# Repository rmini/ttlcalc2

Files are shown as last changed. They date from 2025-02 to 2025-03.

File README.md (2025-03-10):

# TtlCalc2 Project

## Overview

The TtlCalc2 project is a recreation of the original (now TtlCalc1) project from 2005 that implemented a four-function floating point calculator in TTL logic without a microprocessor.

This version uses multilayer PCBs and Nixie tube and neon indicators for the display, whereas the original used wire wrap boards and LED 7-segment displays. Both versions share the same architecture, with separate (Harvard architecture) 8-bit data and 12-bit instruction address spaces, a 4-bit data path, and a 16-bit instruction word.

The goal of the original was to gain experience designing and implementing a processor with these techniques with an eye towards taking on the design of a more capable minicomputer. 

This repository contains the hardware and software components for the TtlCalc2 project, including simulation tools, assembly code, and documentation.

## Board renders

### Main logic board (processor)
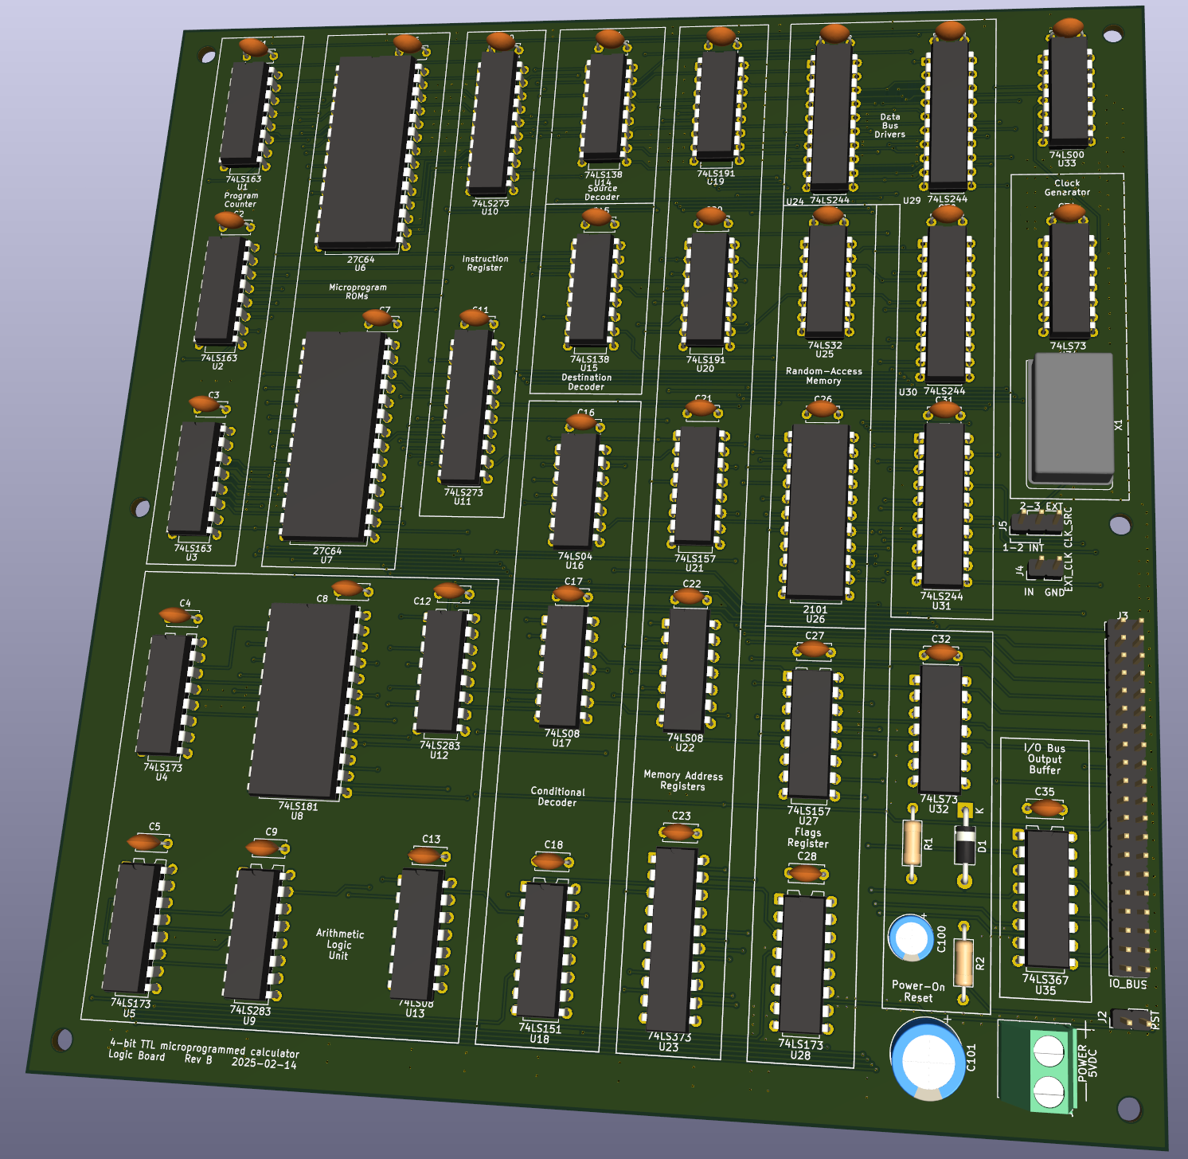
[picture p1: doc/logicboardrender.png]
Main logic board render


### Display driver board
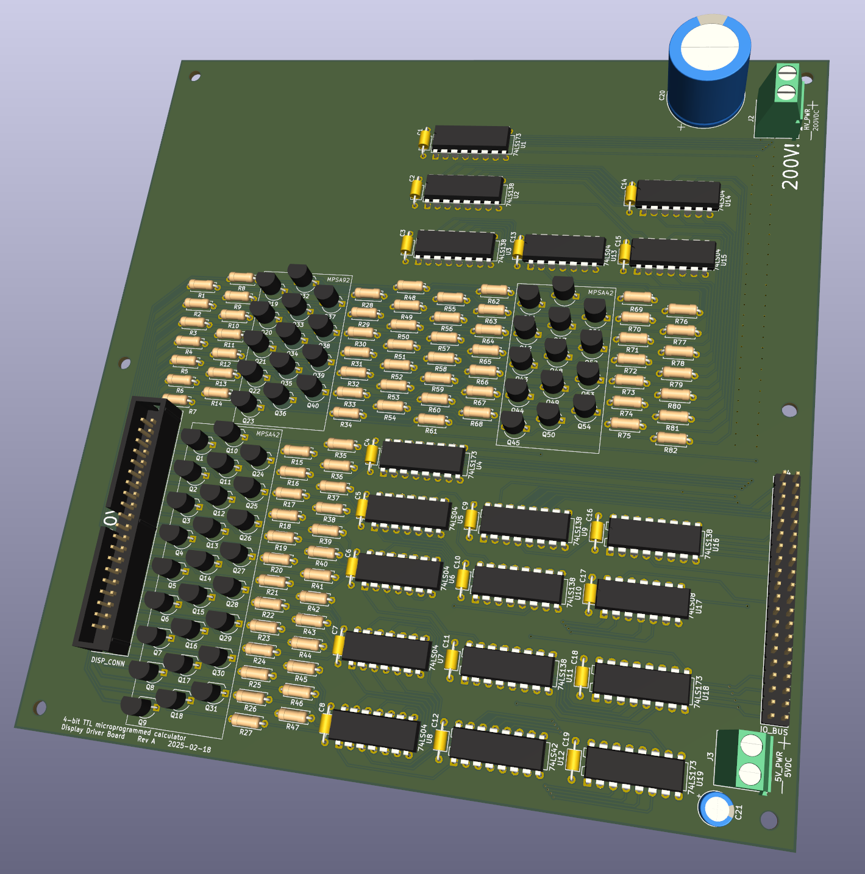
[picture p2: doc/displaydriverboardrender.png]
Display driver board render


### Front panel display board (Nixies and neons)
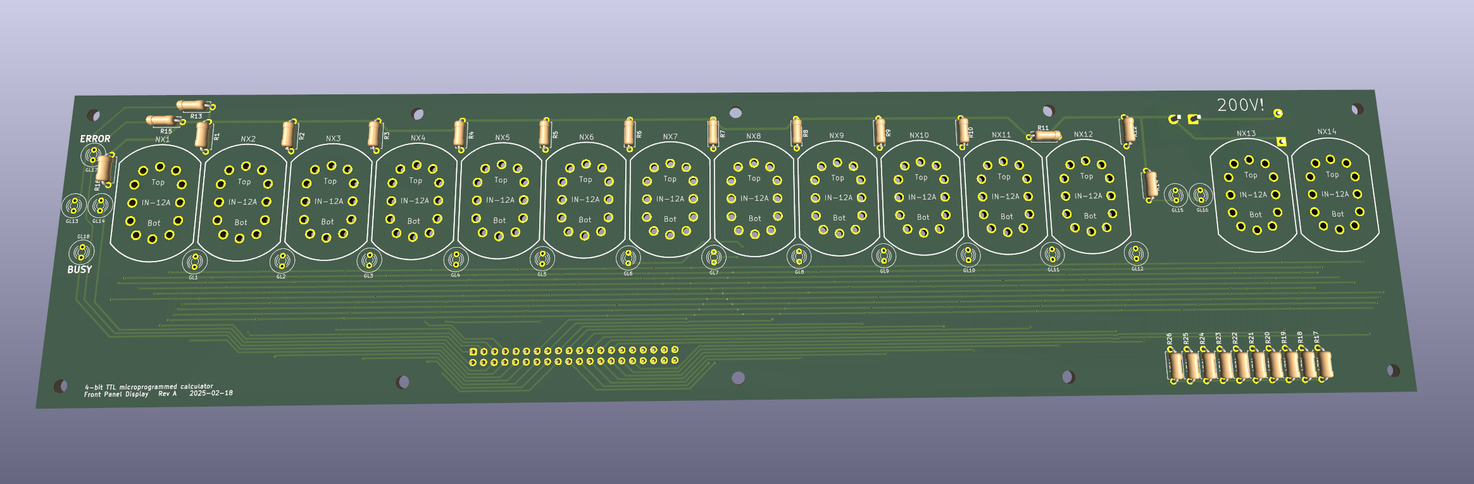
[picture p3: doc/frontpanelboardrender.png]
Front panel display board render


## Directory Structure

 * [`hw/`](hw/): KiCad schematic and PCB designs for the hardware
 * [`sw/`](sw/): Software for the calculator (microinstruction ROMs)
 * [`doc/`](doc/): Design and implementation documentation
 * [`TtlCalcSim/`](TtlCalcSim/): Simulator for the calculator hardware

## Hardware

The [`hw`](hw) directory contains KiCad project files for the TtlCalc2 hardware design.

- [`ttlcalc2/`](hw/ttlcalc2/): Logic board hardware design files.
- [`ttlcalc2_display/`](hw/ttlcalc2_display/): Display driver module design files.
- [`ttlcalc2_front/`](hw/ttlcalc2_front/): Front panel design files.

TODO: The keyboard and keyboard interface still needs to be designed.

### Gerber Files

The `hw/ttlcalc2/gerbers` directory contains the Gerber files for PCB manufacturing.

## Software

The [`sw`](sw/) directory contains assembly code for the TtlCalc2 project. This project uses the [customasm](https://github.com/hlorenzi/customasm) assembler to generate the microcode stream.

- [`ttlcalc2.asm`](sw/ttlcalc2.asm): Mnemonic definitions for the TtlCalc2 microcode.
- [`fib.asm`](sw/fib.asm): Assembly code for calculating Fibonacci numbers.

TODO: Port original ttlcalc assembly source code to new customasm syntax.

### Assembling

For example, to build the Fibonacci code, run:
```sh
customasm fib.asm
```
This generates `fib.bin` which you can then load into the simulator and run.

## Documentation

The [`doc`](doc/) directory contains documentation for the TtlCalc2 project.

## Simulation

The [`TtlCalcSim`](TtlCalcSim/) directory contains the simulation tools for the TtlCalc2 project. The simulator is implemented as a C#/.NET 9.0 console application.

- [`TtlCalcSim/`](TtlCalcSim/TtlCalcSim/): Core simulation library.
- [`TtlCalcSim.ConsoleUI/`](TtlCalcSim/TtlCalcSim.ConsoleUI/): Console-based user interface for the simulator.
- [`TtlCalcSim.Tests/`](TtlCalcSim/TtlCalcSim.Tests/): Unit tests for the simulation library.

### Building the Simulator

To build the simulator, open the TtlCalcSim.sln solution file in Visual Studio and build the project, or use the following command from the TtlCalcSim directory:
```sh
dotnet build
```

### Running Tests

To run the unit tests, use the following command from the TtlCalcSim directory:
```sh
dotnet test
```

### Running the simulator

Either run the simulator executable after building, or run it via the `dotnet` command:
```sh
dotnet run --project TtlCalcSim.ConsoleUI
```

## License

This project is licensed under the MIT License. See the LICENSE file for details.

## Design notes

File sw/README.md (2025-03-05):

# Software for Ttlcalc2

## Assembling

Use customasm from https://github.com/hlorenzi/customasm

For example, to build the Fibonacci code, run `customasm fib.asm`. This generates `fib.bin` which you can then load into the simulator and run.

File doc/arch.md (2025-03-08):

# Overview

The processor is driven by a 16-bit wide microprogram ROM with a 12-bit address. Each instruction directly controls the source that drives the 4-bit data bus and the destination that receives this data. 

Each instruction is either a branch instruction or a data movement instruction.

The ALU is implemented around a 74LS181, a 4-bit arithmetic logic unit (ALU) chip used in many early computers. Additional adders are integrated to allow direct Binary-Coded Decimal (BCD) operations. AND gates are used to provide a flag output for an all-ones result, indicating specific conditions during operations.

RAM and I/O address spaces are separate, but both are driven by the same address registers. The address bus can be driven either from the combined H/L registers or from the 4-bit immediate instruction field via zero-extension. This allows quick access to the first 16 memory and I/O addresses.

# Data path

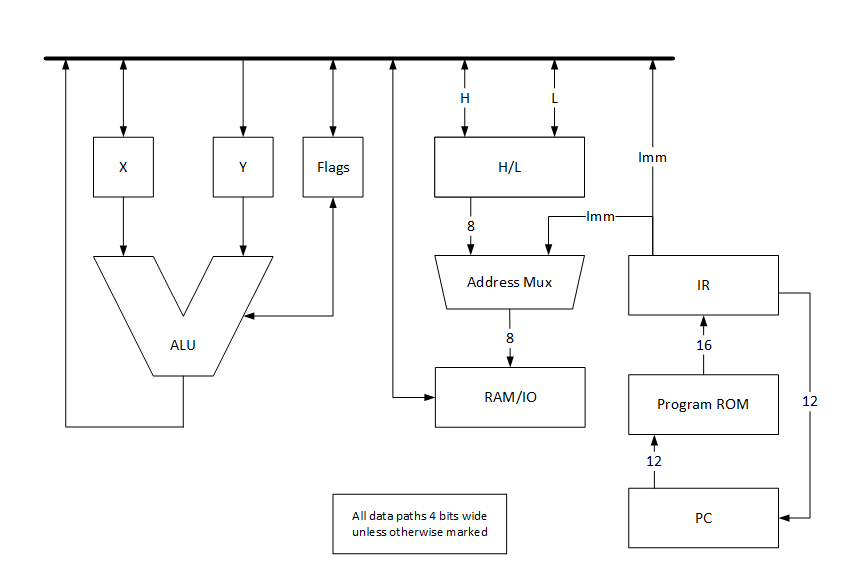
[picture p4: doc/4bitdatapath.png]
data path diagram


## Data Registers

Four-bit registers:

* X, Y: ALU source registers
* Flags (set on ALU operations or explicit target)
  * C: ALU carry in/out (bit 0)
  * E: ALU equal (all ones output) (bit 1)
  * X: Auxiliary flag 1 (bit 2)
  * Y: Auxiliary flag 2 (bit 3)
* H/L: Address registers, combined to make an 8-bit address
  * H: High 4 bits of address (bits 7..4)
  * L: Low 4 bits of address (bits 3..0)
  * Optional post-increment/decrement

## Instruction Registers
* PC: Implemented with a 12-bit presettable counter
* IR: 16-bit 

## Memory
Memory is implemented with an Intel 2101 (or equivalent) 256 x 4-bit NMOS static RAM with separate read and write ports.

## I/O
Separate 4-bit data input and output ports are buffered to and from the internal data bus.

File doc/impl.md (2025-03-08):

# Implementation notes

## Clock and power-on reset logic
The processor uses a two-phase non-overlapping clock derived from a TTL-compatible crystal oscillator module or an external input. This type of clock ensures that there are no overlapping periods where both phases are active, which helps to avoid timing issues and race conditions in the processor's operation. An entire two-phase instruction cycle takes 4 input clock cycles to complete, allowing for precise control and synchronization of the processor's activities. Additionally, a power-on reset circuit keeps the reset line asserted for at least one whole instruction cycle, ensuring that the processor starts in a known state and deasserting at the beginning of the instruction cycle to begin normal operation.

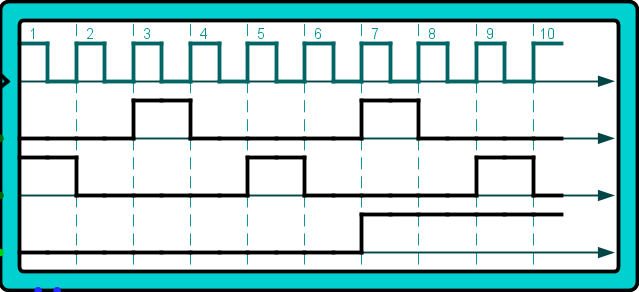
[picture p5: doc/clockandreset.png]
Clock and reset signal plot


In the above plot, the top line is the input clock, the next two are the outputs of the two-phase clock generator circuit, and the bottom line is the active-low reset signal. The input clock drives the two-phase clock generator, producing two non-overlapping clock phases. These phases ensure that certain operations occur in distinct time periods, preventing conflicts. The reset signal is asserted low during power-on, holding the processor in a reset state. Once the reset signal is deasserted, the processor begins normal operation synchronized with the clock phases.

## Clock phases
* Phase 1 rising: Instruction register flip-flop loads the output of the instruction ROMs. 
* Phase 1 falling: Output of the address multiplexer is latched onto the address bus.
* Phase 2 rising: Contents of data bus is latched into destination flip-flops.
* Phase 2 falling: Memory write is de-asserted if destination is memory.

## ALU Circuit and BCD Mode Operations
The Arithmetic Logic Unit (ALU) is responsible for performing arithmetic and logical operations within the processor.

In non-BCD mode, the contents of the X and Y registers are passed unchanged to the 74LS181 ALU inputs. The ALU output is then passed unchanged to the data bus driver. 

BCD mode behavior differs between addition and subtraction.

When adding, the value of the Y register is always pre-incremented by 6 before being passed to the 74LS181 input. This pre-increment ensures that any result greater than 9 will generate a carry, which is necessary for correct BCD addition. Without this pre-increment, the ALU would not correctly handle decimal carries, leading to incorrect results.

When subtracting, the value of the Y register is not pre-incremented because BCD subtraction does not require this adjustment.

For all BCD operations, if there is no carry output, the ALU output is incremented by 10. This is equivalent to subtracting 6 in 2s-complement representation. 

For BCD addition, this adjustment is necessary to correct the result of an addition without carry out. This is because the input was pre-incremented by 6. If there was a carry, the result would need to be incremented by 6 anyway for proper BCD correction. This ensures that the final result is a valid BCD digit.

For BCD subtraction, if there is no carry out, it indicates that Y is larger than X, resulting in a negative output. This means a borrow from the next higher decimal digit is needed, and the result should be incremented by 10.

AND gates connected to the ALU output set the "equal" flag when all bits of the output are set. This is useful in combination with the subtract operation without the carry flag set to effectively compare the X and Y registers. 

The subtract operation is X - Y - 1 + C. When X and Y are equal, the result will be -1. In 2s-complement notation, this results in an output with all bits set. This, along with the carry flag, can be used to determine if Y is less than, greater than, or equal to X.

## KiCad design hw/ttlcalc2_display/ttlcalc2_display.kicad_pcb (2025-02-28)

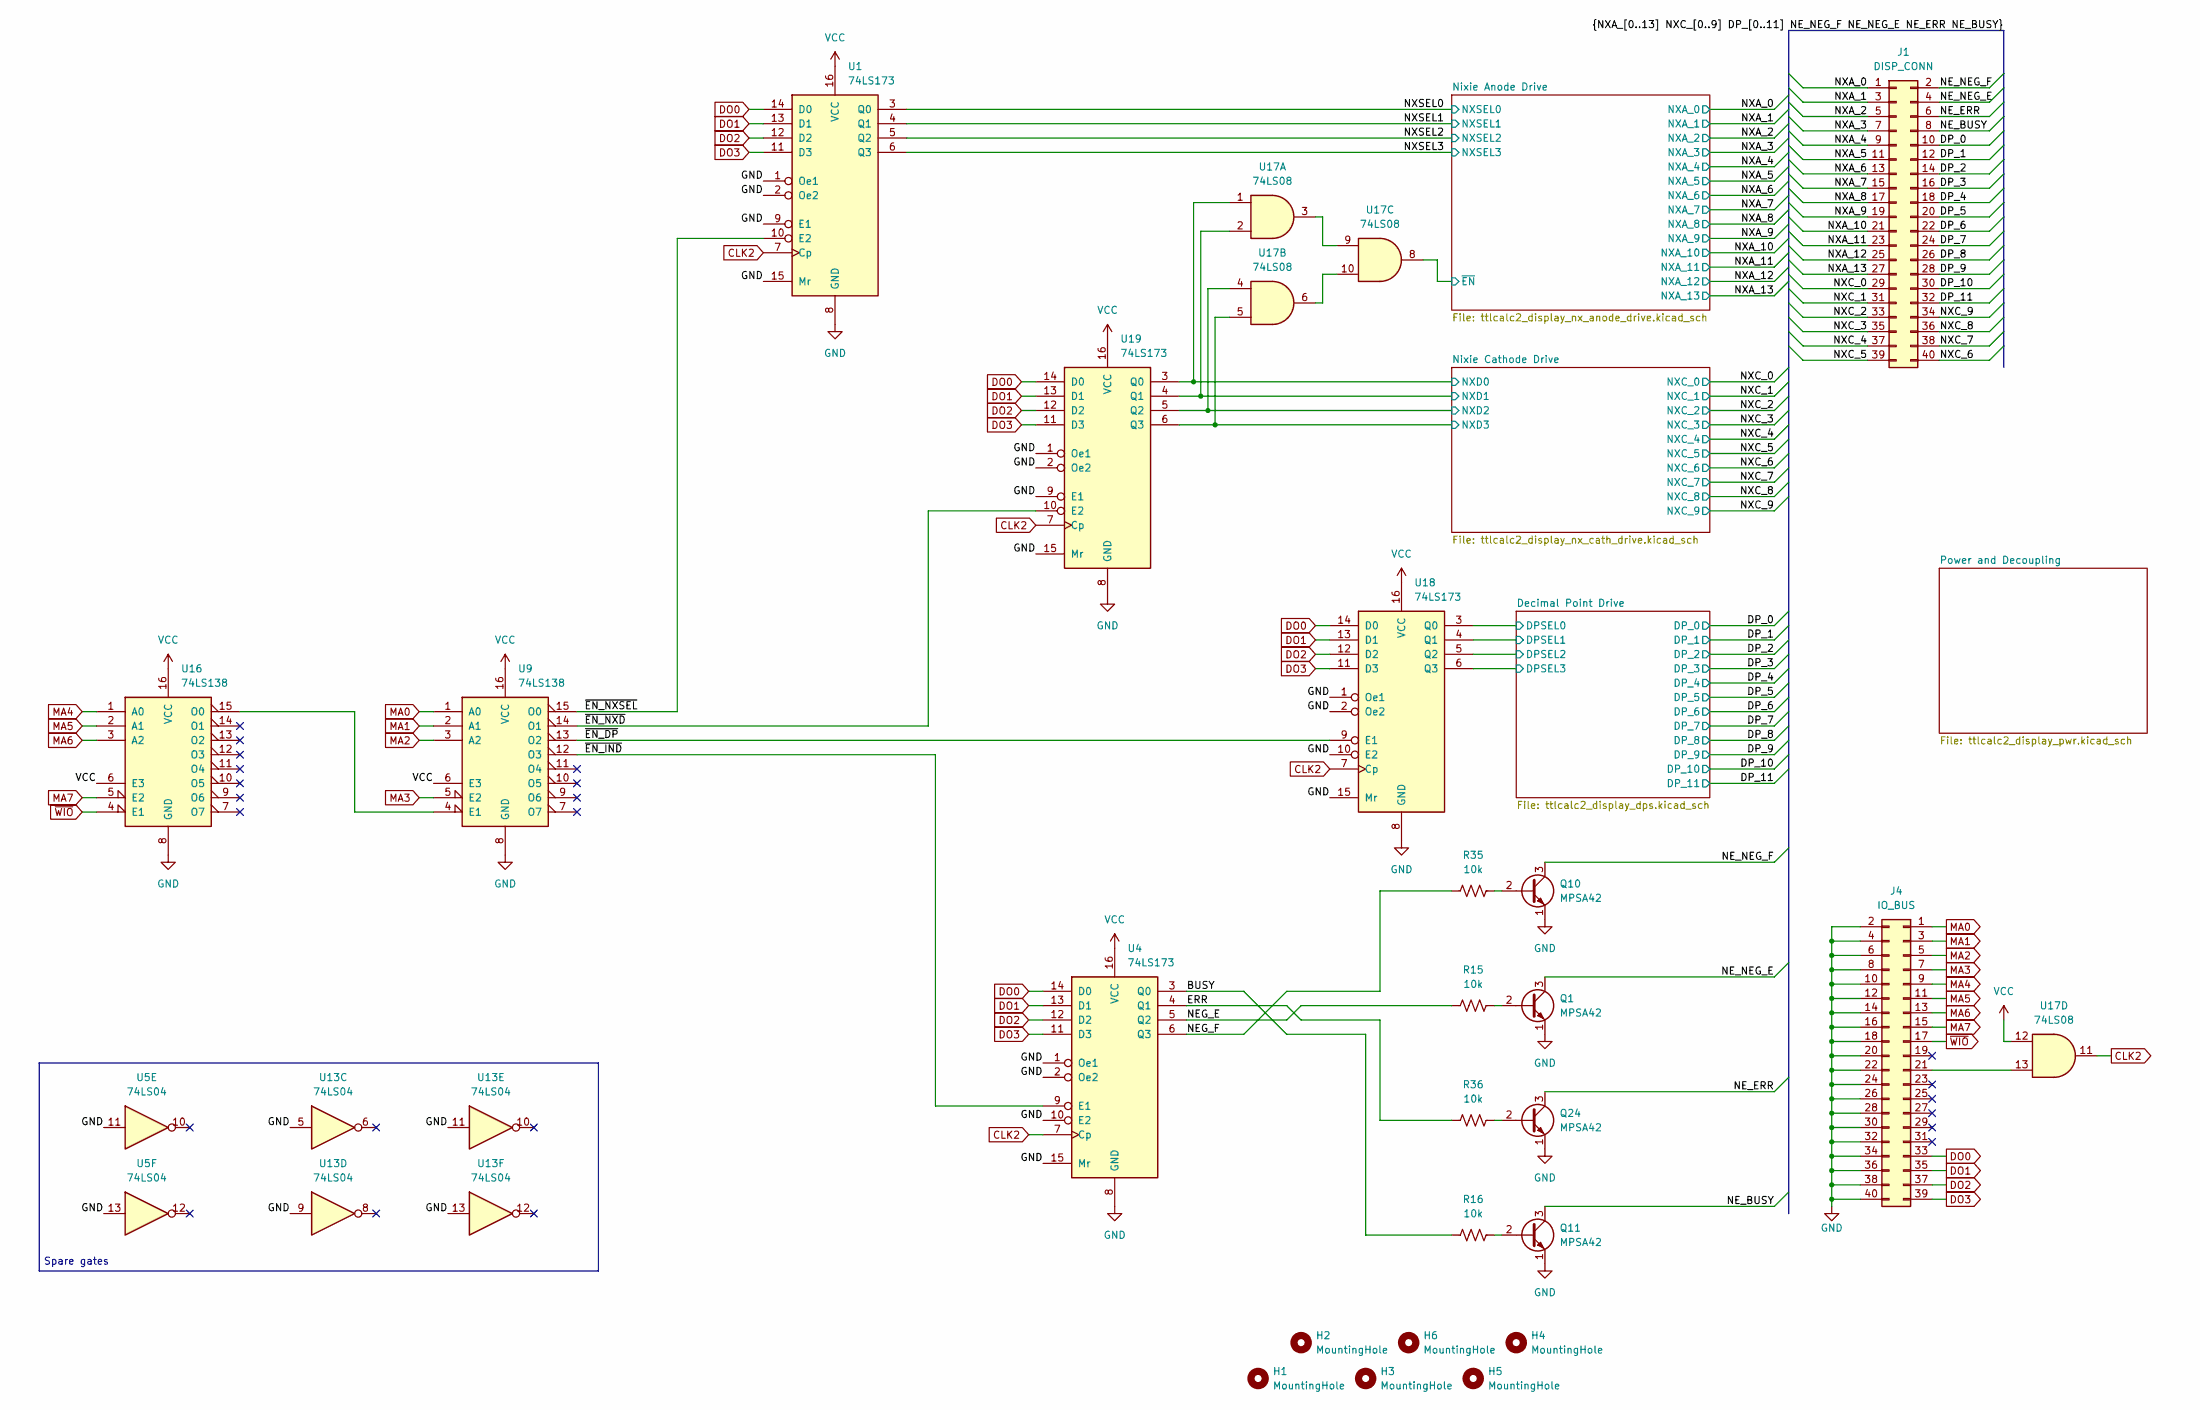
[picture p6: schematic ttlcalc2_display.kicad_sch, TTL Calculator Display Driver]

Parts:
H1, H2, H3, H4, H5, H6: MountingHole; MountingHole_3.2mm_M3
J1: DISP_CONN; IDC-Header_2x20_P2.54mm_Vertical
J4: IO_BUS; PinHeader_2x20_P2.54mm_Vertical
Q1, Q10, Q11, Q24: MPSA42; TO-92_Inline_Wide
R15, R16, R35, R36: 10k; R_Axial_DIN0207_L6.3mm_D2.5mm_P7.62mm_Horizontal
U1, U4, U18, U19: 74LS173; DIP-16_W7.62mm
U5, U13: 74LS04; DIP-14_W7.62mm
U9, U16: 74LS138; DIP-16_W7.62mm
U17: 74LS08; DIP-14_W7.62mm

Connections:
/BUSY: R16.1, U4.3 (Q0)
/DP_0: J1.10; also elsewhere on the board
/DP_1: J1.12; also elsewhere on the board
/DP_2: J1.14; also elsewhere on the board
/DP_3: J1.16; also elsewhere on the board
/DP_4: J1.18; also elsewhere on the board
/DP_5: J1.20; also elsewhere on the board
/DP_6: J1.22; also elsewhere on the board
/DP_7: J1.24; also elsewhere on the board
/DP_8: J1.26; also elsewhere on the board
/DP_9: J1.28; also elsewhere on the board
/DP_10: J1.30; also elsewhere on the board
/DP_11: J1.32; also elsewhere on the board
/Decimal Point Drive/DPSEL0: U18.3 (Q0); also elsewhere on the board
/Decimal Point Drive/DPSEL1: U18.4 (Q1); also elsewhere on the board
/Decimal Point Drive/DPSEL2: U18.5 (Q2); also elsewhere on the board
/Decimal Point Drive/DPSEL3: U18.6 (Q3); also elsewhere on the board
/ERR: R36.1, U4.4 (Q1)
/NEG_E: R15.1, U4.5 (Q2)
/NEG_F: R35.1, U4.6 (Q3)
/NE_BUSY: J1.8, Q11.3 (C)
/NE_ERR: J1.6, Q24.3 (C)
/NE_NEG_E: J1.4, Q1.3 (C)
/NE_NEG_F: J1.2, Q10.3 (C)
/NXA_0: J1.1; also elsewhere on the board
/NXA_1: J1.3; also elsewhere on the board
/NXA_2: J1.5; also elsewhere on the board
/NXA_3: J1.7; also elsewhere on the board
/NXA_4: J1.9; also elsewhere on the board
/NXA_5: J1.11; also elsewhere on the board
/NXA_6: J1.13; also elsewhere on the board
/NXA_7: J1.15; also elsewhere on the board
/NXA_8: J1.17; also elsewhere on the board
/NXA_9: J1.19; also elsewhere on the board
/NXA_10: J1.21; also elsewhere on the board
/NXA_11: J1.23; also elsewhere on the board
/NXA_12: J1.25; also elsewhere on the board
/NXA_13: J1.27; also elsewhere on the board
/NXC_0: J1.29; also elsewhere on the board
/NXC_1: J1.31; also elsewhere on the board
/NXC_2: J1.33; also elsewhere on the board
/NXC_3: J1.35; also elsewhere on the board
/NXC_4: J1.37; also elsewhere on the board
/NXC_5: J1.39; also elsewhere on the board
/NXC_6: J1.40; also elsewhere on the board
/NXC_7: J1.38; also elsewhere on the board
/NXC_8: J1.36; also elsewhere on the board
/NXC_9: J1.34; also elsewhere on the board
/NXSEL0: U1.3 (Q0); also elsewhere on the board
/NXSEL1: U1.4 (Q1); also elsewhere on the board
/NXSEL2: U1.5 (Q2); also elsewhere on the board
/NXSEL3: U1.6 (Q3); also elsewhere on the board
/Nixie Anode Drive/~EN: U17.8; also elsewhere on the board
/Nixie Cathode Drive/NXD0: U17.1, U19.3 (Q0); also elsewhere on the board
/Nixie Cathode Drive/NXD1: U17.2, U19.4 (Q1); also elsewhere on the board
/Nixie Cathode Drive/NXD2: U17.4, U19.5 (Q2); also elsewhere on the board
/Nixie Cathode Drive/NXD3: U17.5, U19.6 (Q3); also elsewhere on the board
/~EN_DP: U9.13 (O2), U18.9 (E1)
/~EN_IND: U4.9 (E1), U9.12 (O3)
/~EN_NXD: U9.14 (O1), U19.10 (E2)
/~EN_NXSEL: U1.10 (E2), U9.15 (O0)
CLK2: U1.7 (Cp), U4.7 (Cp), U17.11, U18.7 (Cp), U19.7 (Cp)
DO0: J4.33, U1.14 (D0), U4.14 (D0), U18.14 (D0), U19.14 (D0)
DO1: J4.35, U1.13 (D1), U4.13 (D1), U18.13 (D1), U19.13 (D1)
DO2: J4.37, U1.12 (D2), U4.12 (D2), U18.12 (D2), U19.12 (D2)
DO3: J4.39, U1.11 (D3), U4.11 (D3), U18.11 (D3), U19.11 (D3)
GND: J4.2, J4.4, J4.6, J4.8, J4.10, J4.12, J4.14, J4.16, J4.18, J4.20, J4.22, J4.24, J4.26, J4.28, J4.30, J4.32, J4.34, J4.36, J4.38, J4.40, Q1.1 (E), Q10.1 (E), Q11.1 (E), Q24.1 (E), U1.1 (Oe1), U1.2 (Oe2), U1.8 (GND), U1.9 (E1), U1.15 (Mr), U4.1 (Oe1), U4.2 (Oe2), U4.8 (GND), U4.10 (E2), U4.15 (Mr), U5.11, U5.13, U9.8 (GND), U13.5, U13.9, U13.11, U13.13, U16.8 (GND), U18.1 (Oe1), U18.2 (Oe2), U18.8 (GND), U18.10 (E2), U18.15 (Mr), U19.1 (Oe1), U19.2 (Oe2), U19.8 (GND), U19.9 (E1), U19.15 (Mr); also elsewhere on the board
MA0: J4.1, U9.1 (A0)
MA1: J4.3, U9.2 (A1)
MA2: J4.5, U9.3 (A2)
MA3: J4.7, U9.5 (E2)
MA4: J4.9, U16.1 (A0)
MA5: J4.11, U16.2 (A1)
MA6: J4.13, U16.3 (A2)
MA7: J4.15, U16.5 (E2)
unnamed: J4.21, U17.13
unnamed: Q1.2 (B), R15.2
unnamed: Q10.2 (B), R35.2
unnamed: Q11.2 (B), R16.2
unnamed: Q24.2 (B), R36.2
unnamed: U9.4 (E1), U16.15 (O0)
unnamed: U17.3, U17.9
unnamed: U17.6, U17.10
VCC: U1.16 (VCC), U4.16 (VCC), U9.6 (E3), U9.16 (VCC), U16.6 (E3), U16.16 (VCC), U17.12, U18.16 (VCC), U19.16 (VCC); also elsewhere on the board
~WIO: J4.17, U16.4 (E1)

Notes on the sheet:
Spare gates

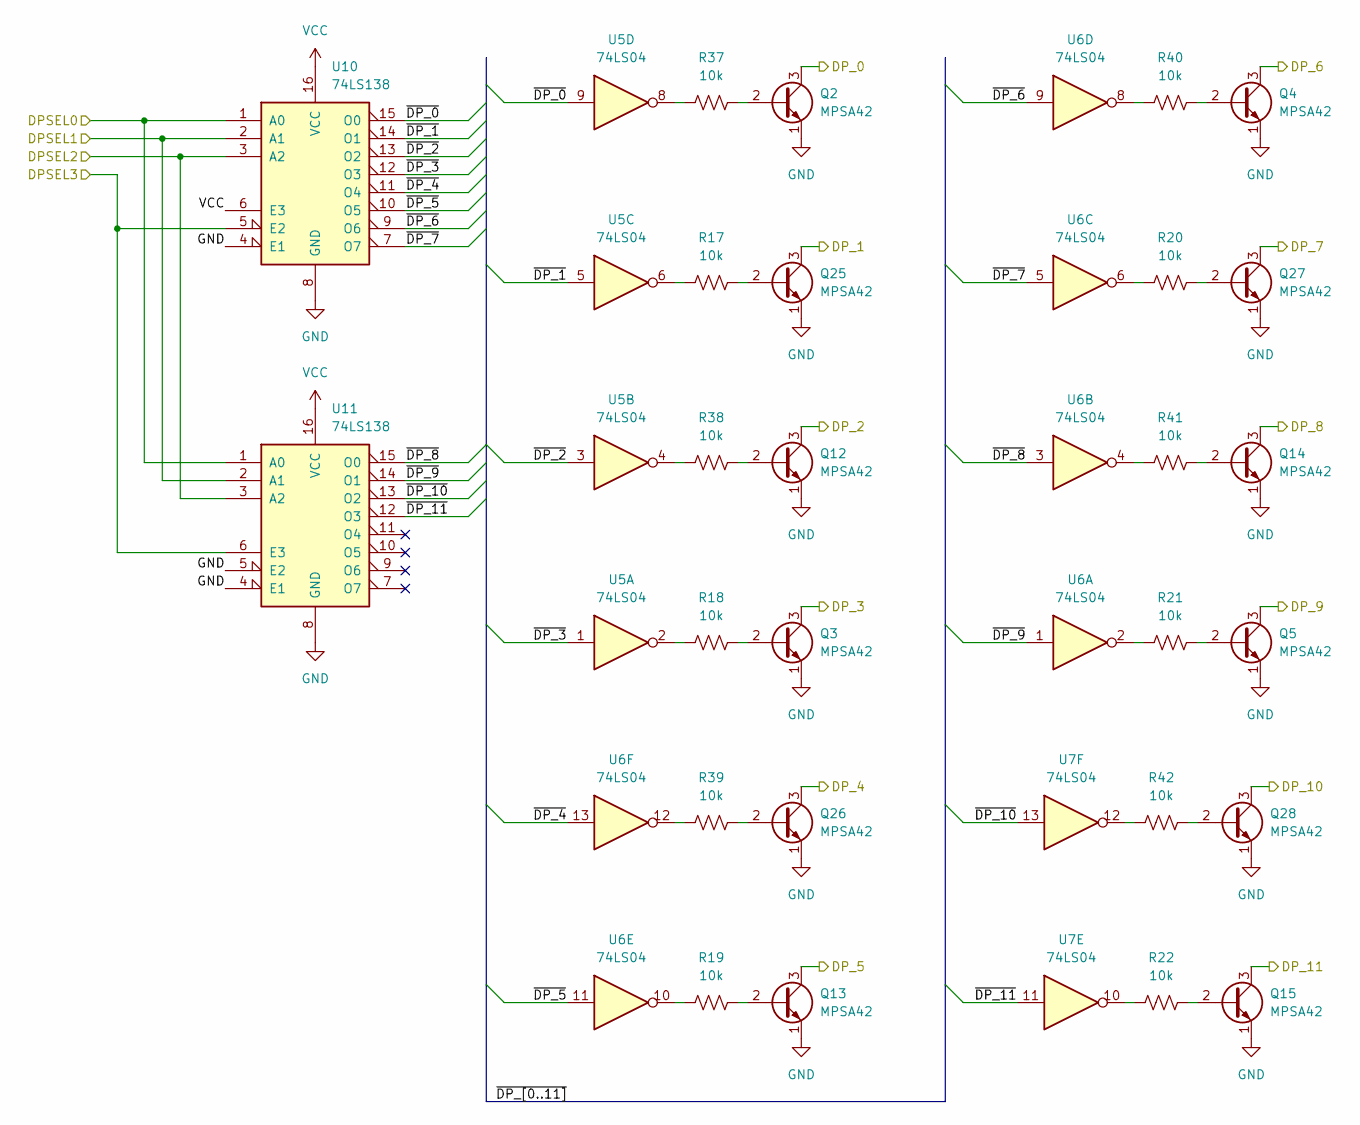
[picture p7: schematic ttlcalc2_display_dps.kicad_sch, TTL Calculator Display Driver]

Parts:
Q2, Q3, Q4, Q5, Q12, Q13, Q14, Q15, Q25, Q26, Q27, Q28: MPSA42; TO-92_Inline_Wide
R17, R18, R19, R20, R21, R22, R37, R38, R39, R40, R41, R42: 10k; R_Axial_DIN0207_L6.3mm_D2.5mm_P7.62mm_Horizontal
U5, U6, U7: 74LS04; DIP-14_W7.62mm
U10, U11: 74LS138; DIP-16_W7.62mm

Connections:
/DP_0: Q2.3 (C); also elsewhere on the board
/DP_1: Q25.3 (C); also elsewhere on the board
/DP_2: Q12.3 (C); also elsewhere on the board
/DP_3: Q3.3 (C); also elsewhere on the board
/DP_4: Q26.3 (C); also elsewhere on the board
/DP_5: Q13.3 (C); also elsewhere on the board
/DP_6: Q4.3 (C); also elsewhere on the board
/DP_7: Q27.3 (C); also elsewhere on the board
/DP_8: Q14.3 (C); also elsewhere on the board
/DP_9: Q5.3 (C); also elsewhere on the board
/DP_10: Q28.3 (C); also elsewhere on the board
/DP_11: Q15.3 (C); also elsewhere on the board
/Decimal Point Drive/DPSEL0: U10.1 (A0), U11.1 (A0); also elsewhere on the board
/Decimal Point Drive/DPSEL1: U10.2 (A1), U11.2 (A1); also elsewhere on the board
/Decimal Point Drive/DPSEL2: U10.3 (A2), U11.3 (A2); also elsewhere on the board
/Decimal Point Drive/DPSEL3: U10.5 (E2), U11.6 (E3); also elsewhere on the board
/Decimal Point Drive/~DP_0: U5.9, U10.15 (O0)
/Decimal Point Drive/~DP_1: U5.5, U10.14 (O1)
/Decimal Point Drive/~DP_2: U5.3, U10.13 (O2)
/Decimal Point Drive/~DP_3: U5.1, U10.12 (O3)
/Decimal Point Drive/~DP_4: U6.13, U10.11 (O4)
/Decimal Point Drive/~DP_5: U6.11, U10.10 (O5)
/Decimal Point Drive/~DP_6: U6.9, U10.9 (O6)
/Decimal Point Drive/~DP_7: U6.5, U10.7 (O7)
/Decimal Point Drive/~DP_8: U6.3, U11.15 (O0)
/Decimal Point Drive/~DP_9: U6.1, U11.14 (O1)
/Decimal Point Drive/~DP_10: U7.13, U11.13 (O2)
/Decimal Point Drive/~DP_11: U7.11, U11.12 (O3)
GND: Q2.1 (E), Q3.1 (E), Q4.1 (E), Q5.1 (E), Q12.1 (E), Q13.1 (E), Q14.1 (E), Q15.1 (E), Q25.1 (E), Q26.1 (E), Q27.1 (E), Q28.1 (E), U10.4 (E1), U10.8 (GND), U11.4 (E1), U11.5 (E2), U11.8 (GND); also elsewhere on the board
unnamed: Q2.2 (B), R37.2
unnamed: Q3.2 (B), R18.2
unnamed: Q4.2 (B), R40.2
unnamed: Q5.2 (B), R21.2
unnamed: Q12.2 (B), R38.2
unnamed: Q13.2 (B), R19.2
unnamed: Q14.2 (B), R41.2
unnamed: Q15.2 (B), R22.2
unnamed: Q25.2 (B), R17.2
unnamed: Q26.2 (B), R39.2
unnamed: Q27.2 (B), R20.2
unnamed: Q28.2 (B), R42.2
unnamed: R17.1, U5.6
unnamed: R18.1, U5.2
unnamed: R19.1, U6.10
unnamed: R20.1, U6.6
unnamed: R21.1, U6.2
unnamed: R22.1, U7.10
unnamed: R37.1, U5.8
unnamed: R38.1, U5.4
unnamed: R39.1, U6.12
unnamed: R40.1, U6.8
unnamed: R41.1, U6.4
unnamed: R42.1, U7.12
VCC: U10.6 (E3), U10.16 (VCC), U11.16 (VCC); also elsewhere on the board

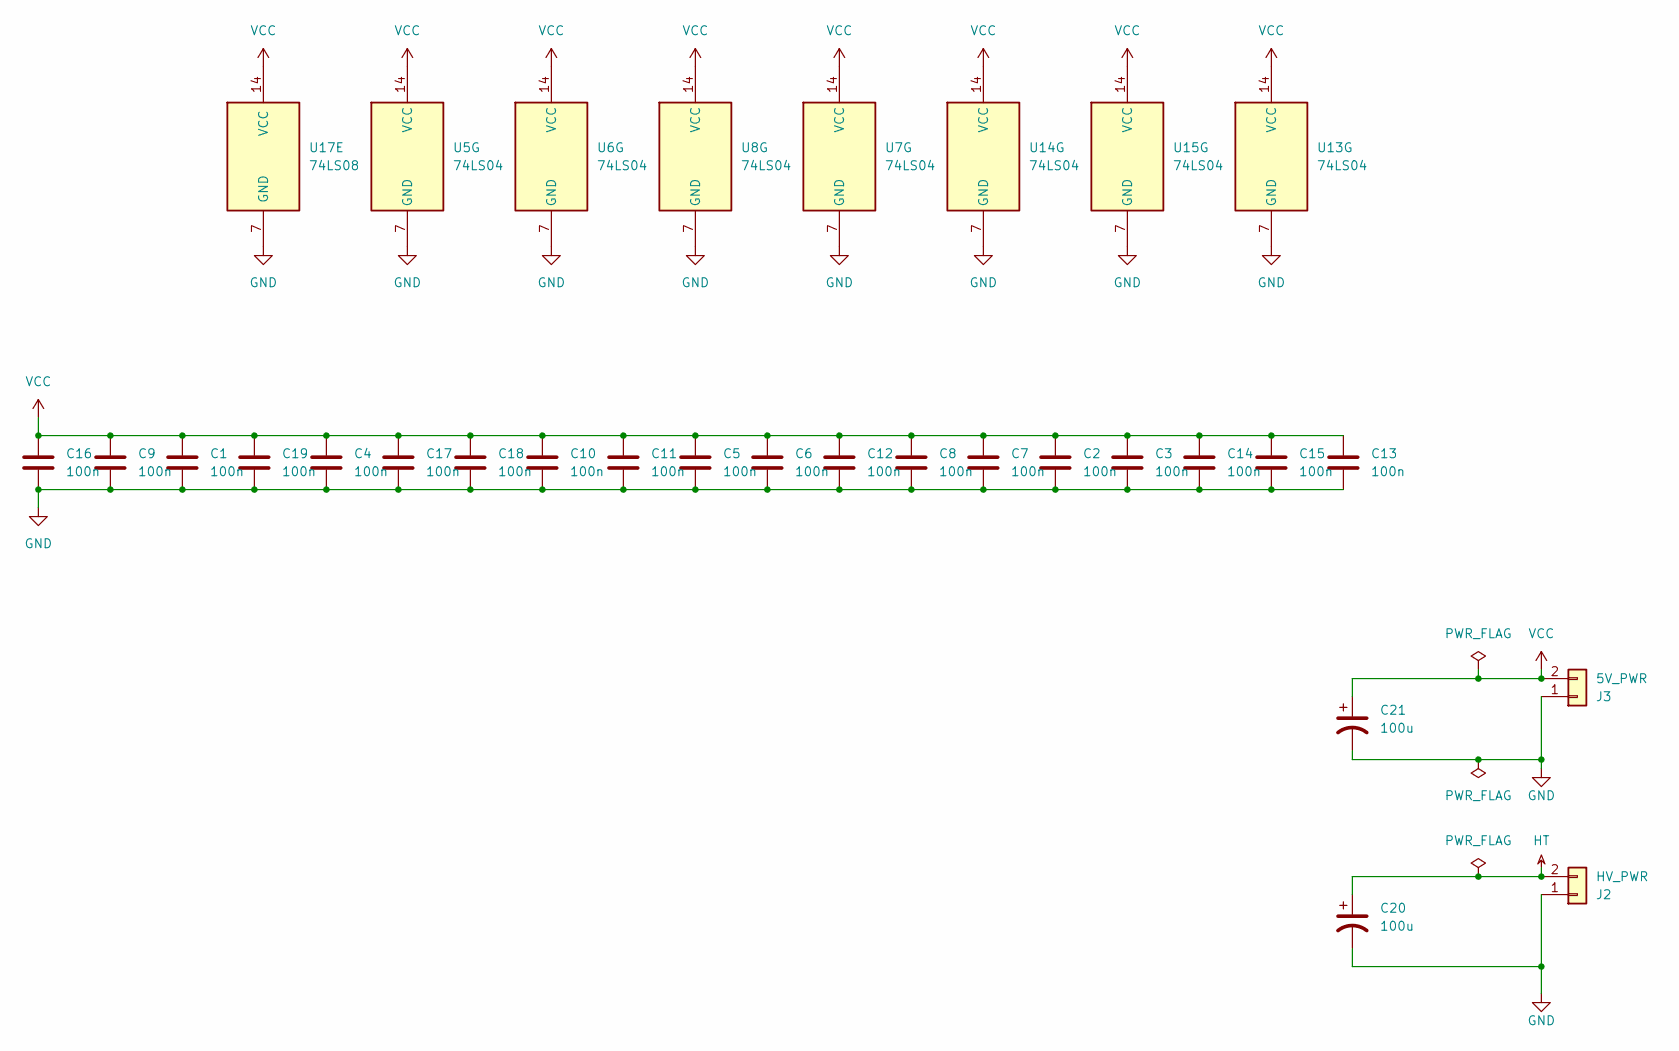
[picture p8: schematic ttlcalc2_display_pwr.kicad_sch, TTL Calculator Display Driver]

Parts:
C1, C2, C3, C4, C5, C6, C7, C8, C9, C10, C11, C12, C13, C14, C15, C16, C17, C18, C19: 100n; C_Axial_L3.8mm_D2.6mm_P7.50mm_Horizontal
C20: 100u; CP_Radial_D18.0mm_P7.50mm
C21: 100u; CP_Radial_D6.3mm_P2.50mm
J2: HV_PWR; TerminalBlock_Phoenix_MKDS-1,5-2-5.08_1x02_P5.08mm_Horizont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
J3: 5V_PWR; TerminalBlock_Phoenix_MKDS-1,5-2-5.08_1x02_P5.08mm_Horizont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
U5, U6, U7, U8, U13, U14, U15: 74LS04; DIP-14_W7.62mm
U17: 74LS08; DIP-14_W7.62mm

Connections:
GND: C1.2, C2.2, C3.2, C4.2, C5.2, C6.2, C7.2, C8.2, C9.2, C10.2, C11.2, C12.2, C13.2, C14.2, C15.2, C16.2, C17.2, C18.2, C19.2, C20.2, C21.2, J2.1, J3.1, U5.7 (GND), U6.7 (GND), U7.7 (GND), U8.7 (GND), U13.7 (GND), U14.7 (GND), U15.7 (GND), U17.7 (GND); also elsewhere on the board
HT: C20.1, J2.2; also elsewhere on the board
VCC: C1.1, C2.1, C3.1, C4.1, C5.1, C6.1, C7.1, C8.1, C9.1, C10.1, C11.1, C12.1, C13.1, C14.1, C15.1, C16.1, C17.1, C18.1, C19.1, C21.1, J3.2, U5.14 (VCC), U6.14 (VCC), U7.14 (VCC), U8.14 (VCC), U13.14 (VCC), U14.14 (VCC), U15.14 (VCC), U17.14 (VCC); also elsewhere on the board

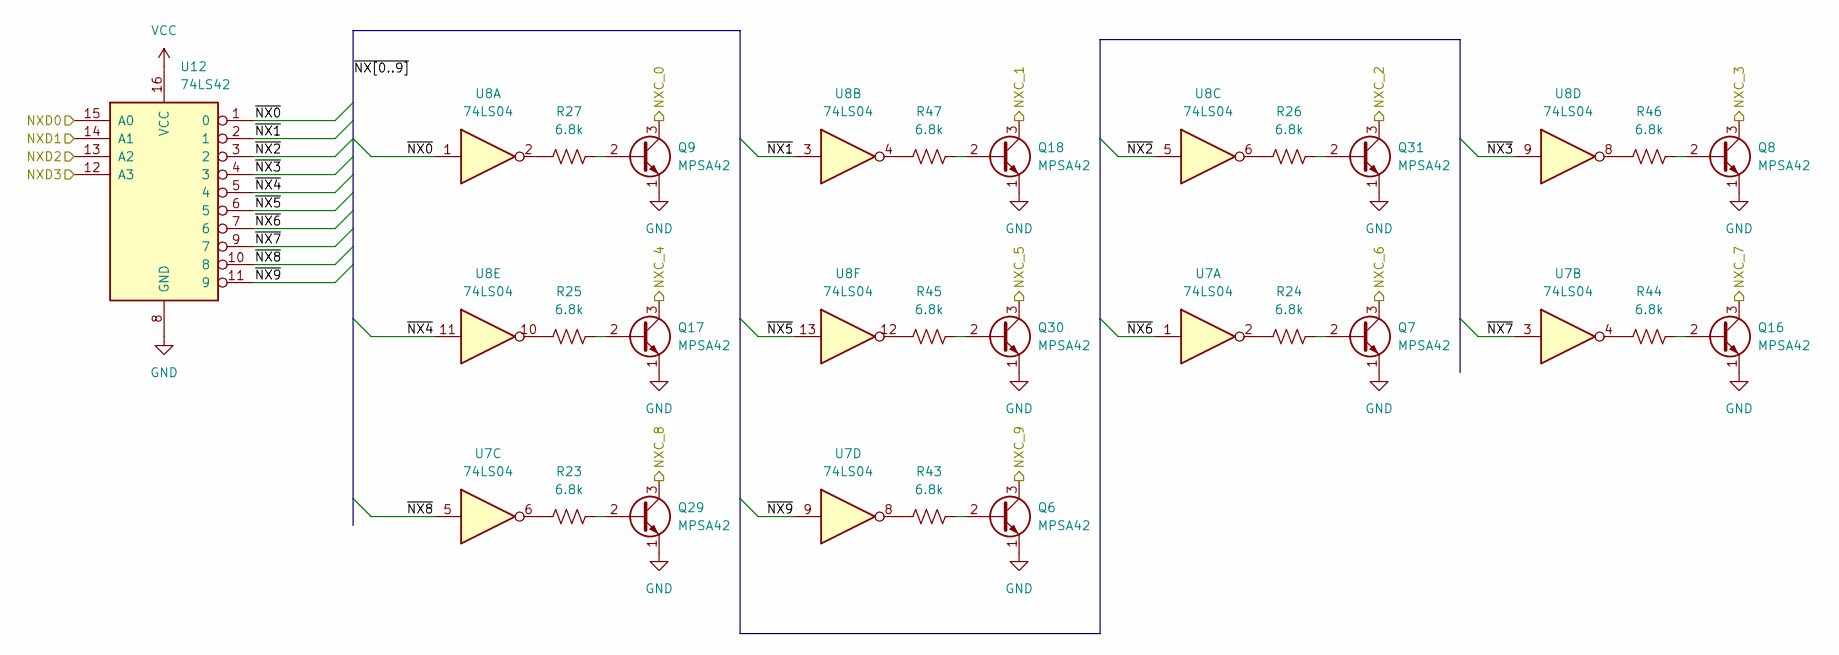
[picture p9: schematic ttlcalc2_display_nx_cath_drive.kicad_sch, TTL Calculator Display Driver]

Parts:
Q6, Q7, Q8, Q9, Q16, Q17, Q18, Q29, Q30, Q31: MPSA42; TO-92_Inline_Wide
R23, R24, R25, R26, R27, R43, R44, R45, R46, R47: 6.8k; R_Axial_DIN0207_L6.3mm_D2.5mm_P7.62mm_Horizontal
U7, U8: 74LS04; DIP-14_W7.62mm
U12: 74LS42; DIP-16_W7.62mm

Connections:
/NXC_0: Q9.3 (C); also elsewhere on the board
/NXC_1: Q18.3 (C); also elsewhere on the board
/NXC_2: Q31.3 (C); also elsewhere on the board
/NXC_3: Q8.3 (C); also elsewhere on the board
/NXC_4: Q17.3 (C); also elsewhere on the board
/NXC_5: Q30.3 (C); also elsewhere on the board
/NXC_6: Q7.3 (C); also elsewhere on the board
/NXC_7: Q16.3 (C); also elsewhere on the board
/NXC_8: Q29.3 (C); also elsewhere on the board
/NXC_9: Q6.3 (C); also elsewhere on the board
/Nixie Cathode Drive/NXD0: U12.15 (A0); also elsewhere on the board
/Nixie Cathode Drive/NXD1: U12.14 (A1); also elsewhere on the board
/Nixie Cathode Drive/NXD2: U12.13 (A2); also elsewhere on the board
/Nixie Cathode Drive/NXD3: U12.12 (A3); also elsewhere on the board
/Nixie Cathode Drive/~NX0: U8.1, U12.1 (0)
/Nixie Cathode Drive/~NX1: U8.3, U12.2 (1)
/Nixie Cathode Drive/~NX2: U8.5, U12.3 (2)
/Nixie Cathode Drive/~NX3: U8.9, U12.4 (3)
/Nixie Cathode Drive/~NX4: U8.11, U12.5 (4)
/Nixie Cathode Drive/~NX5: U8.13, U12.6 (5)
/Nixie Cathode Drive/~NX6: U7.1, U12.7 (6)
/Nixie Cathode Drive/~NX7: U7.3, U12.9 (7)
/Nixie Cathode Drive/~NX8: U7.5, U12.10 (8)
/Nixie Cathode Drive/~NX9: U7.9, U12.11 (9)
GND: Q6.1 (E), Q7.1 (E), Q8.1 (E), Q9.1 (E), Q16.1 (E), Q17.1 (E), Q18.1 (E), Q29.1 (E), Q30.1 (E), Q31.1 (E), U12.8 (GND); also elsewhere on the board
unnamed: Q6.2 (B), R43.2
unnamed: Q7.2 (B), R24.2
unnamed: Q8.2 (B), R46.2
unnamed: Q9.2 (B), R27.2
unnamed: Q16.2 (B), R44.2
unnamed: Q17.2 (B), R25.2
unnamed: Q18.2 (B), R47.2
unnamed: Q29.2 (B), R23.2
unnamed: Q30.2 (B), R45.2
unnamed: Q31.2 (B), R26.2
unnamed: R23.1, U7.6
unnamed: R24.1, U7.2
unnamed: R25.1, U8.10
unnamed: R26.1, U8.6
unnamed: R27.1, U8.2
unnamed: R43.1, U7.8
unnamed: R44.1, U7.4
unnamed: R45.1, U8.12
unnamed: R46.1, U8.8
unnamed: R47.1, U8.4
VCC: U12.16 (VCC); also elsewhere on the board

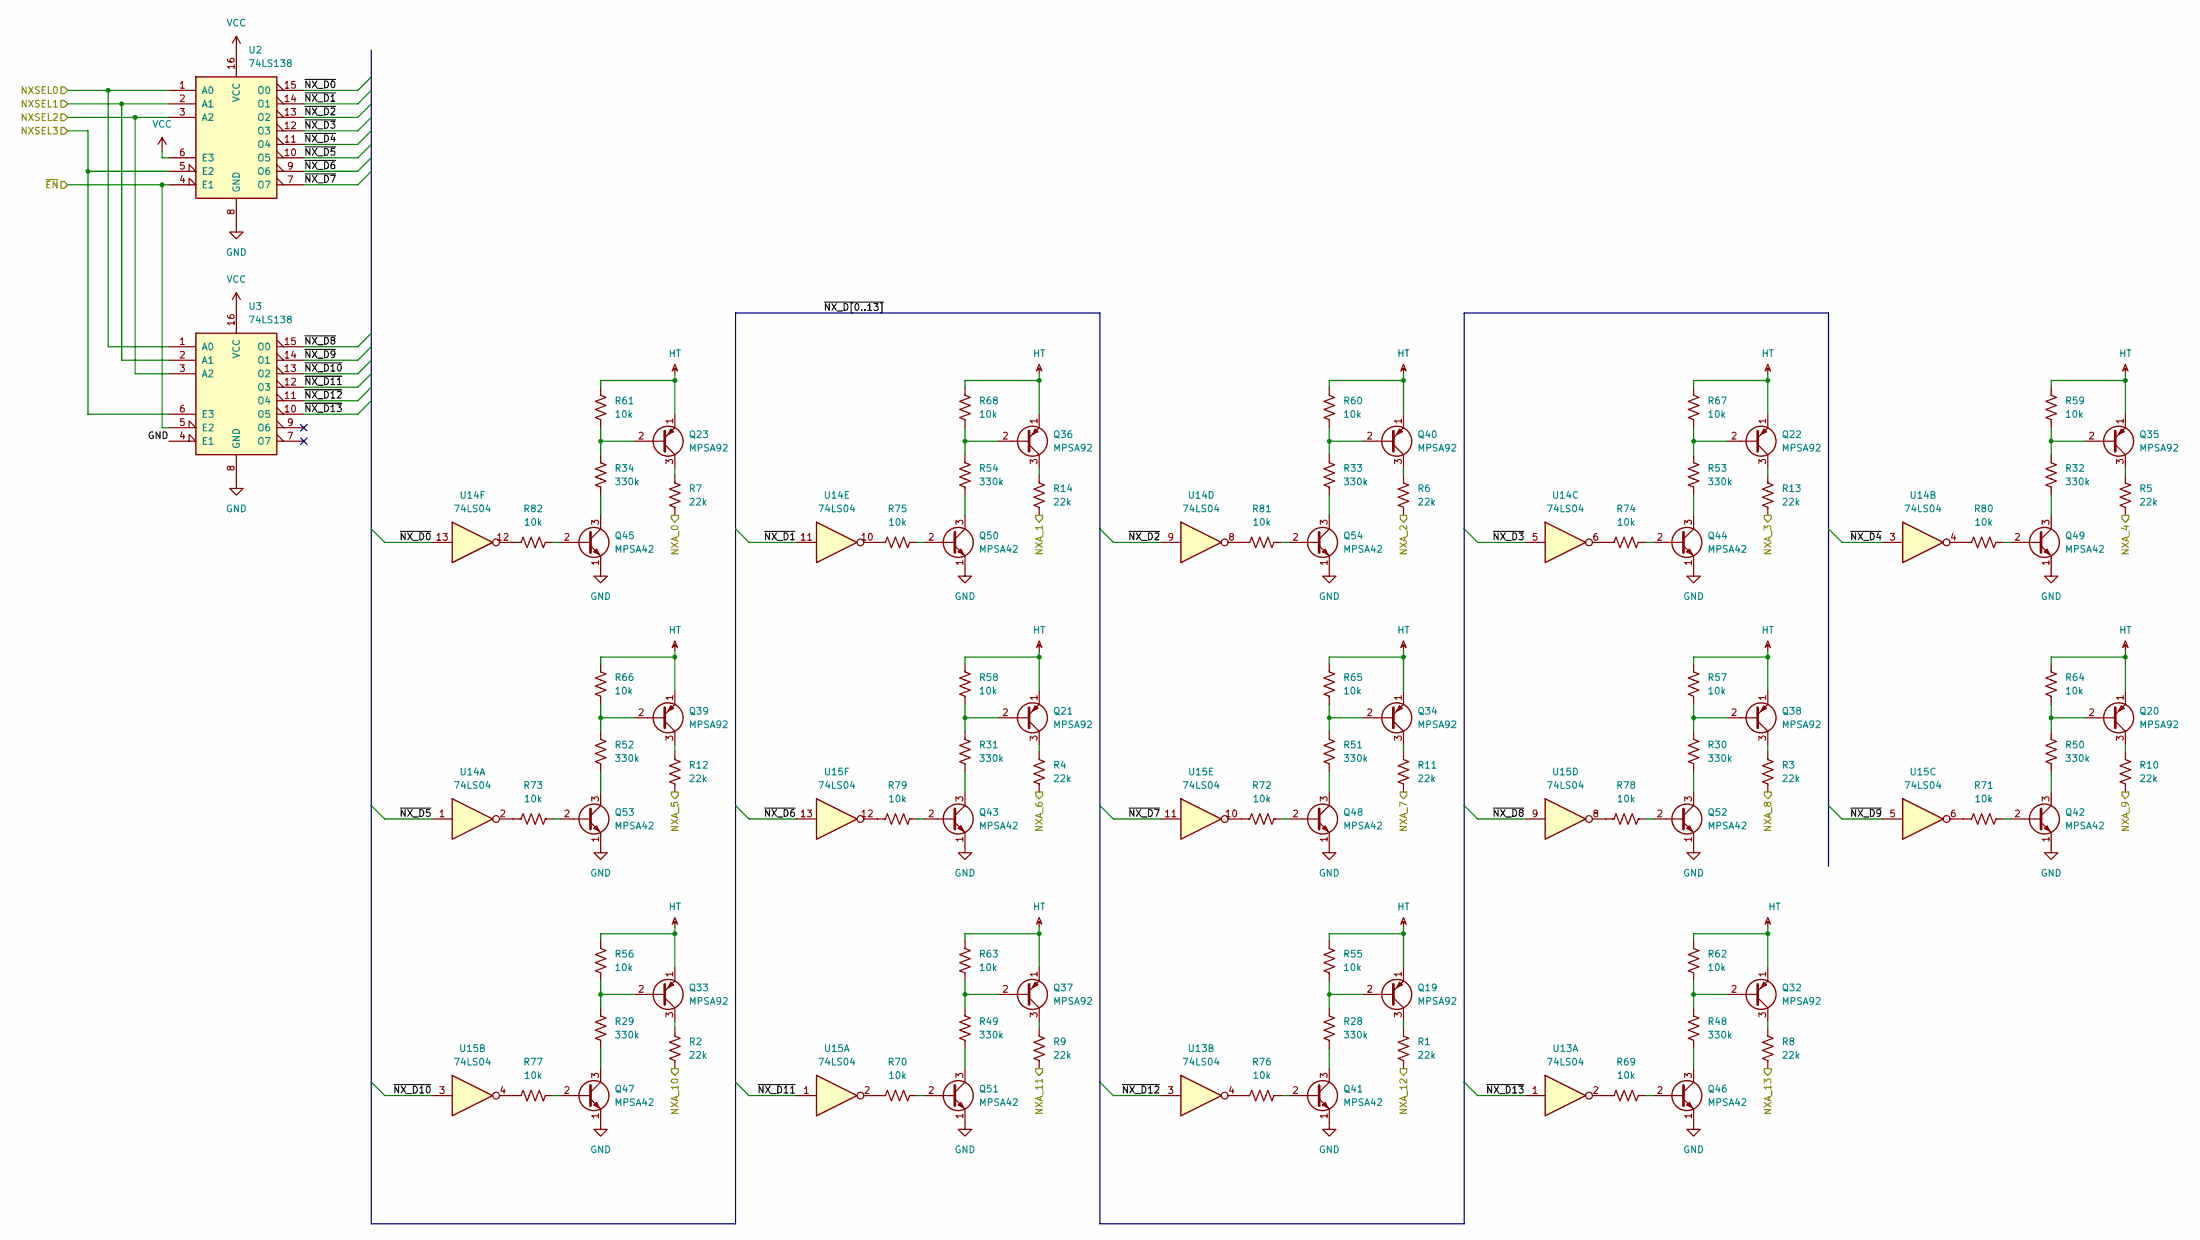
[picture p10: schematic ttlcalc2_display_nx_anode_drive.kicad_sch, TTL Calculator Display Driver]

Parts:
Q19, Q20, Q21, Q22, Q23, Q32, Q33, Q34, Q35, Q36, Q37, Q38, Q39, Q40: MPSA92; TO-92_Inline_Wide
Q41, Q42, Q43, Q44, Q45, Q46, Q47, Q48, Q49, Q50, Q51, Q52, Q53, Q54: MPSA42; TO-92_Inline_Wide
R1, R2, R3, R4, R5, R6, R7, R8, R9, R10, R11, R12, R13, R14: 22k; R_Axial_DIN0207_L6.3mm_D2.5mm_P7.62mm_Horizontal
R28, R29, R30, R31, R32, R33, R34, R48, R49, R50, R51, R52, R53, R54: 330k; R_Axial_DIN0207_L6.3mm_D2.5mm_P7.62mm_Horizontal
R55, R56, R57, R58, R59, R60, R61, R62, R63, R64, R65, R66, R67, R68, R69, R70, R71, R72, R73, R74, R75, R76, R77, R78, R79, R80, R81, R82: 10k; R_Axial_DIN0207_L6.3mm_D2.5mm_P7.62mm_Horizontal
U2, U3: 74LS138; DIP-16_W7.62mm
U13, U14, U15: 74LS04; DIP-14_W7.62mm

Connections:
/NXA_0: R7.2; also elsewhere on the board
/NXA_1: R14.2; also elsewhere on the board
/NXA_2: R6.2; also elsewhere on the board
/NXA_3: R13.2; also elsewhere on the board
/NXA_4: R5.2; also elsewhere on the board
/NXA_5: R12.2; also elsewhere on the board
/NXA_6: R4.2; also elsewhere on the board
/NXA_7: R11.2; also elsewhere on the board
/NXA_8: R3.2; also elsewhere on the board
/NXA_9: R10.2; also elsewhere on the board
/NXA_10: R2.2; also elsewhere on the board
/NXA_11: R9.2; also elsewhere on the board
/NXA_12: R1.2; also elsewhere on the board
/NXA_13: R8.2; also elsewhere on the board
/NXSEL0: U2.1 (A0), U3.1 (A0); also elsewhere on the board
/NXSEL1: U2.2 (A1), U3.2 (A1); also elsewhere on the board
/NXSEL2: U2.3 (A2), U3.3 (A2); also elsewhere on the board
/NXSEL3: U2.5 (E2), U3.6 (E3); also elsewhere on the board
/Nixie Anode Drive/~EN: U2.4 (E1), U3.5 (E2); also elsewhere on the board
/Nixie Anode Drive/~NX_D0: U2.15 (O0), U14.13
/Nixie Anode Drive/~NX_D1: U2.14 (O1), U14.11
/Nixie Anode Drive/~NX_D2: U2.13 (O2), U14.9
/Nixie Anode Drive/~NX_D3: U2.12 (O3), U14.5
/Nixie Anode Drive/~NX_D4: U2.11 (O4), U14.3
/Nixie Anode Drive/~NX_D5: U2.10 (O5), U14.1
/Nixie Anode Drive/~NX_D6: U2.9 (O6), U15.13
/Nixie Anode Drive/~NX_D7: U2.7 (O7), U15.11
/Nixie Anode Drive/~NX_D8: U3.15 (O0), U15.9
/Nixie Anode Drive/~NX_D9: U3.14 (O1), U15.5
/Nixie Anode Drive/~NX_D10: U3.13 (O2), U15.3
/Nixie Anode Drive/~NX_D11: U3.12 (O3), U15.1
/Nixie Anode Drive/~NX_D12: U3.11 (O4), U13.3
/Nixie Anode Drive/~NX_D13: U3.10 (O5), U13.1
GND: Q41.1 (E), Q42.1 (E), Q43.1 (E), Q44.1 (E), Q45.1 (E), Q46.1 (E), Q47.1 (E), Q48.1 (E), Q49.1 (E), Q50.1 (E), Q51.1 (E), Q52.1 (E), Q53.1 (E), Q54.1 (E), U2.8 (GND), U3.4 (E1), U3.8 (GND); also elsewhere on the board
HT: Q19.1 (E), Q20.1 (E), Q21.1 (E), Q22.1 (E), Q23.1 (E), Q32.1 (E), Q33.1 (E), Q34.1 (E), Q35.1 (E), Q36.1 (E), Q37.1 (E), Q38.1 (E), Q39.1 (E), Q40.1 (E), R55.1, R56.1, R57.1, R58.1, R59.1, R60.1, R61.1, R62.1, R63.1, R64.1, R65.1, R66.1, R67.1, R68.1; also elsewhere on the board
unnamed: Q19.2 (B), R28.1, R55.2
unnamed: Q19.3 (C), R1.1
unnamed: Q20.2 (B), R50.1, R64.2
unnamed: Q20.3 (C), R10.1
unnamed: Q21.2 (B), R31.1, R58.2
unnamed: Q21.3 (C), R4.1
unnamed: Q22.2 (B), R53.1, R67.2
unnamed: Q22.3 (C), R13.1
unnamed: Q23.2 (B), R34.1, R61.2
unnamed: Q23.3 (C), R7.1
unnamed: Q32.2 (B), R48.1, R62.2
unnamed: Q32.3 (C), R8.1
unnamed: Q33.2 (B), R29.1, R56.2
unnamed: Q33.3 (C), R2.1
unnamed: Q34.2 (B), R51.1, R65.2
unnamed: Q34.3 (C), R11.1
unnamed: Q35.2 (B), R32.1, R59.2
unnamed: Q35.3 (C), R5.1
unnamed: Q36.2 (B), R54.1, R68.2
unnamed: Q36.3 (C), R14.1
unnamed: Q37.2 (B), R49.1, R63.2
unnamed: Q37.3 (C), R9.1
unnamed: Q38.2 (B), R30.1, R57.2
unnamed: Q38.3 (C), R3.1
unnamed: Q39.2 (B), R52.1, R66.2
unnamed: Q39.3 (C), R12.1
unnamed: Q40.2 (B), R33.1, R60.2
unnamed: Q40.3 (C), R6.1
unnamed: Q41.2 (B), R76.2
unnamed: Q41.3 (C), R28.2
unnamed: Q42.2 (B), R71.2
unnamed: Q42.3 (C), R50.2
unnamed: Q43.2 (B), R79.2
unnamed: Q43.3 (C), R31.2
unnamed: Q44.2 (B), R74.2
unnamed: Q44.3 (C), R53.2
unnamed: Q45.2 (B), R82.2
unnamed: Q45.3 (C), R34.2
unnamed: Q46.2 (B), R69.2
unnamed: Q46.3 (C), R48.2
unnamed: Q47.2 (B), R77.2
unnamed: Q47.3 (C), R29.2
unnamed: Q48.2 (B), R72.2
unnamed: Q48.3 (C), R51.2
unnamed: Q49.2 (B), R80.2
unnamed: Q49.3 (C), R32.2
unnamed: Q50.2 (B), R75.2
unnamed: Q50.3 (C), R54.2
unnamed: Q51.2 (B), R70.2
unnamed: Q51.3 (C), R49.2
unnamed: Q52.2 (B), R78.2
unnamed: Q52.3 (C), R30.2
unnamed: Q53.2 (B), R73.2
unnamed: Q53.3 (C), R52.2
unnamed: Q54.2 (B), R81.2
unnamed: Q54.3 (C), R33.2
unnamed: R69.1, U13.2
unnamed: R70.1, U15.2
unnamed: R71.1, U15.6
unnamed: R72.1, U15.10
unnamed: R73.1, U14.2
unnamed: R74.1, U14.6
unnamed: R75.1, U14.10
unnamed: R76.1, U13.4
unnamed: R77.1, U15.4
unnamed: R78.1, U15.8
unnamed: R79.1, U15.12
unnamed: R80.1, U14.4
unnamed: R81.1, U14.8
unnamed: R82.1, U14.12
VCC: U2.6 (E3), U2.16 (VCC), U3.16 (VCC); also elsewhere on the board

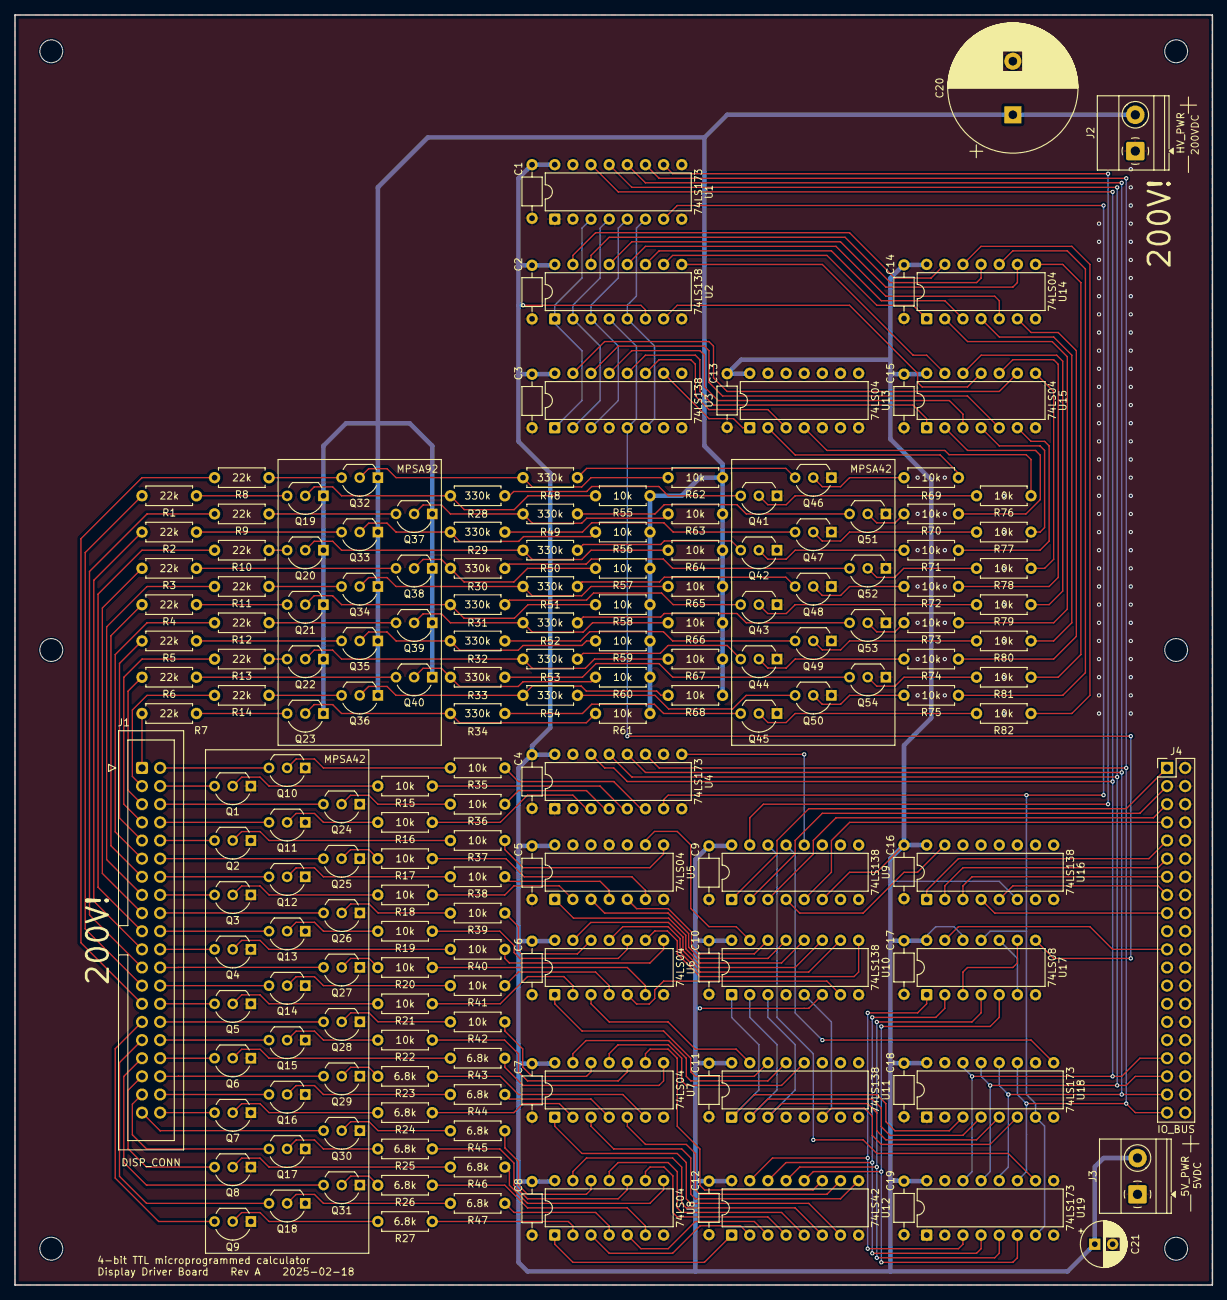
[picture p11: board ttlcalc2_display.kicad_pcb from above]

Board: 2 copper layers, 167.6 x 177.8 mm, 186 parts (0 on the bottom side), 236 nets.

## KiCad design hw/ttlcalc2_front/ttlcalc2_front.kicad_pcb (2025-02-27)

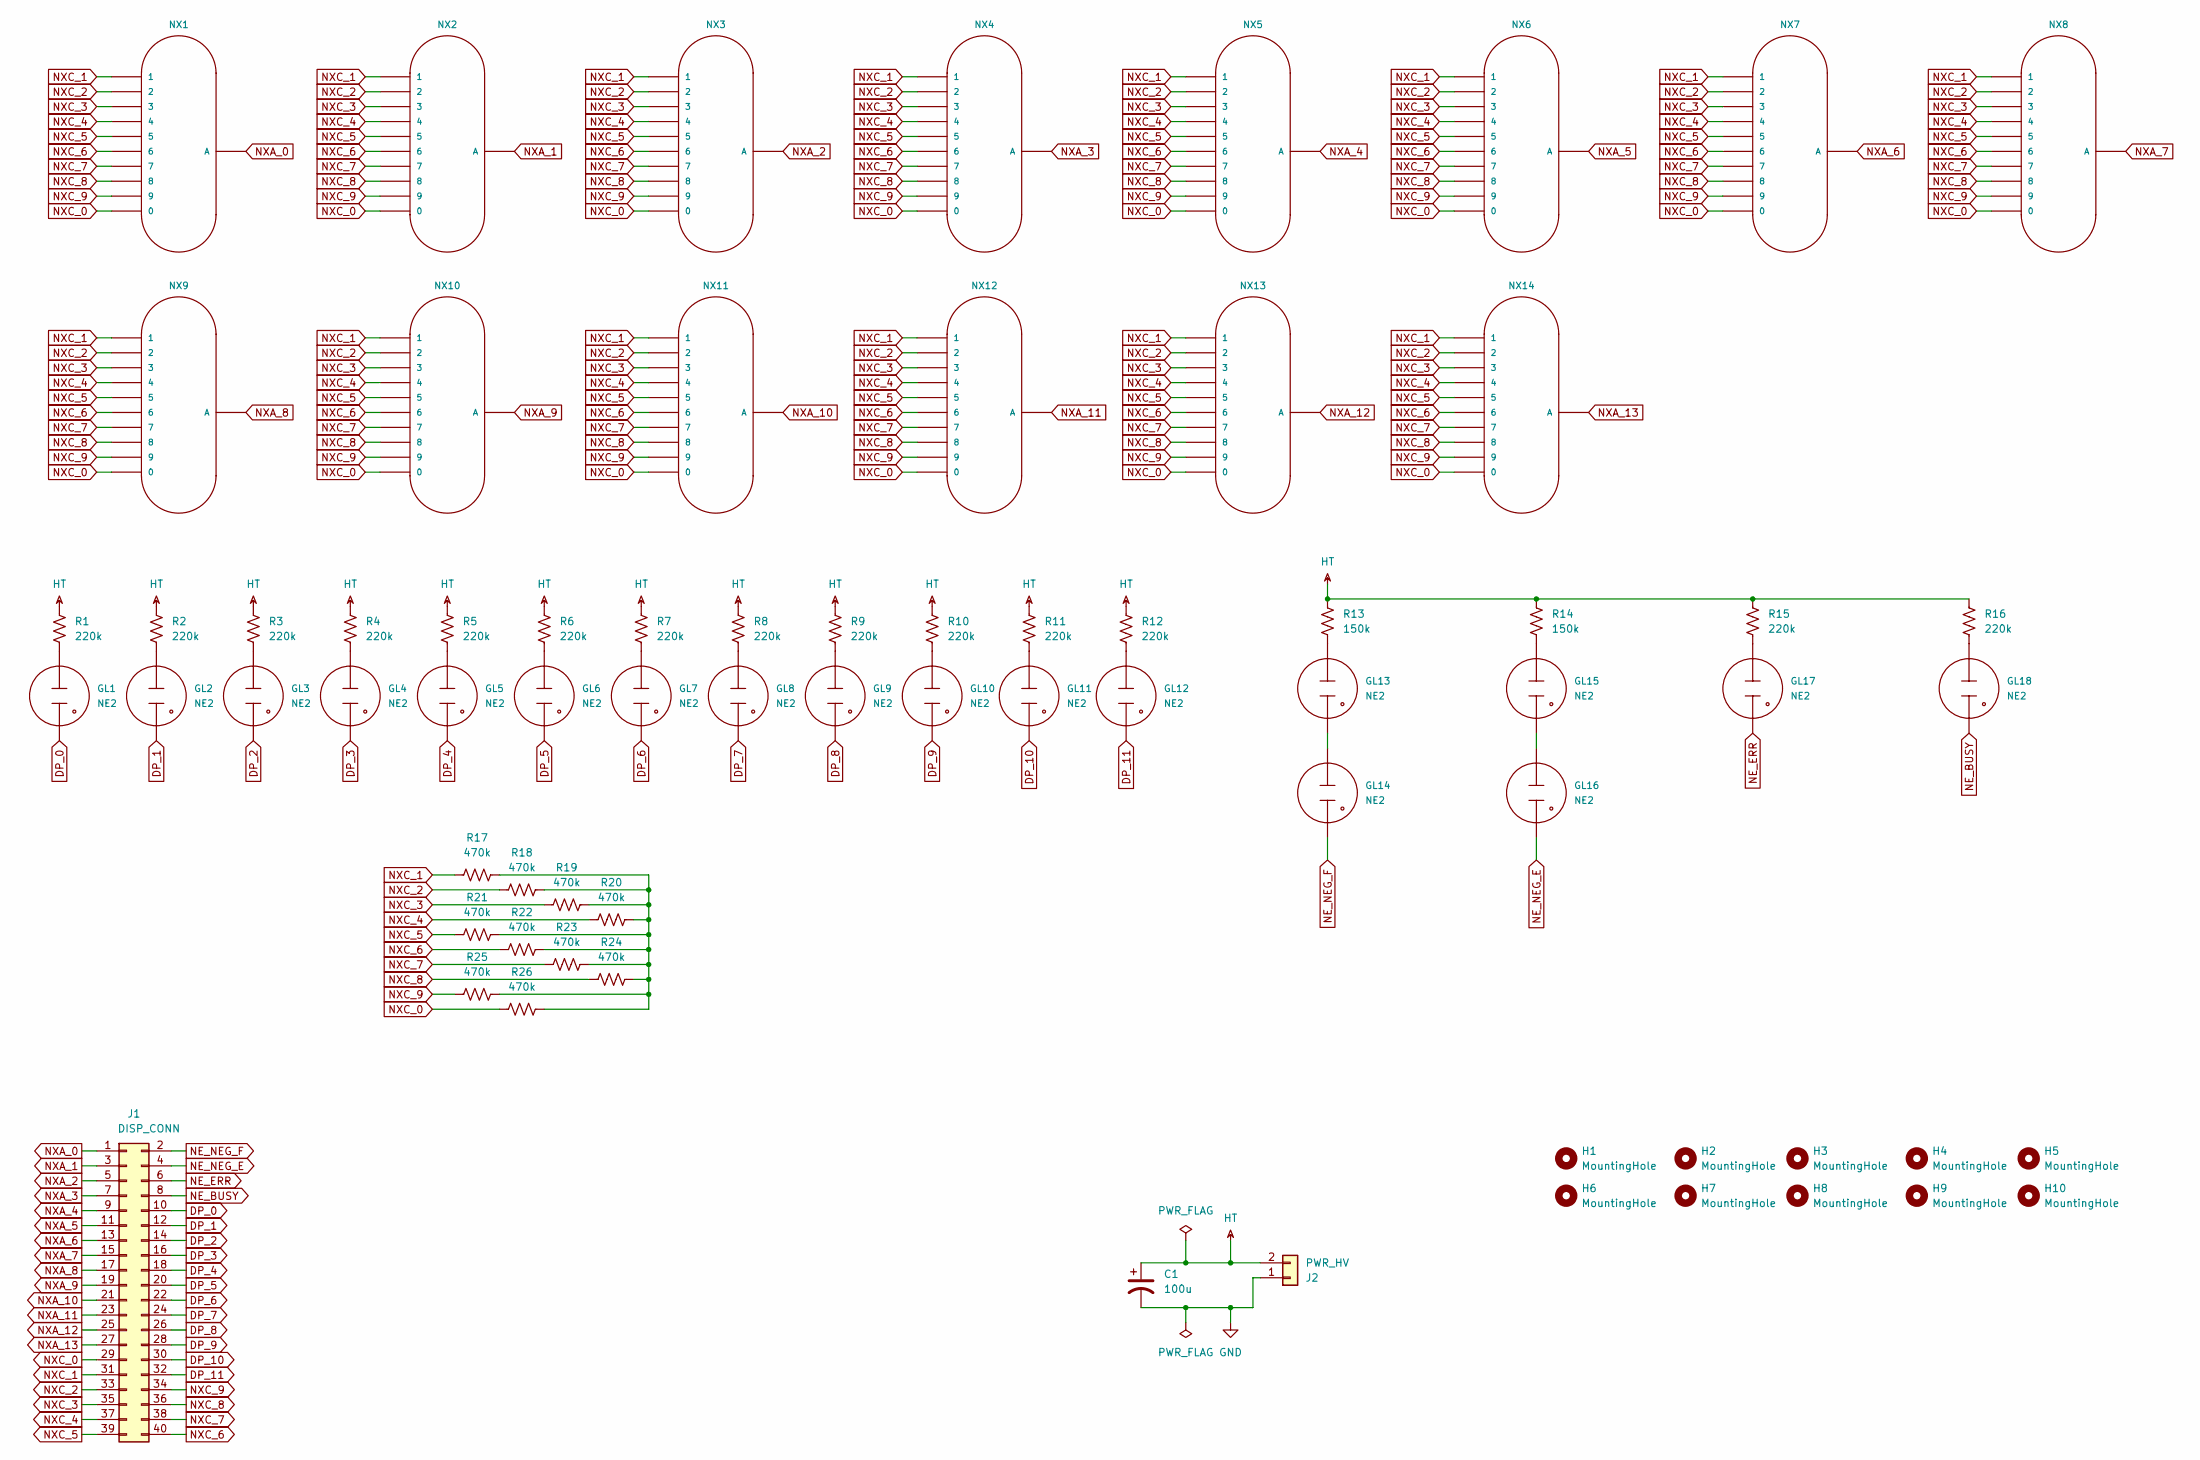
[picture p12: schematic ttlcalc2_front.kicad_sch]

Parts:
C1: 100u; CP_Radial_D18.0mm_P7.50mm
GL1, GL2, GL3, GL4, GL5, GL6, GL7, GL8, GL9, GL10, GL11, GL12, GL13, GL14, GL15, GL16, GL17, GL18: NE2; mynixies-NE2-NEON-BULB-DRILL
H1, H2, H3, H4, H5, H6, H7, H8, H9, H10: MountingHole; MountingHole_3.2mm_M3
J1: DISP_CONN; IDC-Header_2x20_P2.54mm_Vertical
J2: PWR_HV; TerminalBlock_Phoenix_MKDS-1,5-2-5.08_1x02_P5.08mm_Horizont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
NX1, NX2, NX3, NX4, NX5, NX6, NX7, NX8, NX9, NX10, NX11, NX12, NX13, NX14: IN-12A; nixies-us-IN-12-DSUB-NOHOLE
R1, R2, R3, R4, R5, R6, R7, R8, R9, R10, R11, R12, R15, R16: 220k; R_Axial_DIN0207_L6.3mm_D2.5mm_P7.62mm_Horizontal
R13, R14: 150k; R_Axial_DIN0207_L6.3mm_D2.5mm_P7.62mm_Horizontal
R17, R18, R19, R20, R21, R22, R23, R24, R25, R26: 470k; R_Axial_DIN0207_L6.3mm_D2.5mm_P7.62mm_Horizontal

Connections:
DP_0: GL1.2 (A1), J1.10
DP_1: GL2.2 (A1), J1.12
DP_2: GL3.2 (A1), J1.14
DP_3: GL4.2 (A1), J1.16
DP_4: GL5.2 (A1), J1.18
DP_5: GL6.2 (A1), J1.20
DP_6: GL7.2 (A1), J1.22
DP_7: GL8.2 (A1), J1.24
DP_8: GL9.2 (A1), J1.26
DP_9: GL10.2 (A1), J1.28
DP_10: GL11.2 (A1), J1.30
DP_11: GL12.2 (A1), J1.32
GND: C1.2, J2.1
HT: C1.1, J2.2, R1.1, R2.1, R3.1, R4.1, R5.1, R6.1, R7.1, R8.1, R9.1, R10.1, R11.1, R12.1, R13.1, R14.1, R15.1, R16.1
NE_BUSY: GL18.2 (A1), J1.8
NE_ERR: GL17.2 (A1), J1.6
NE_NEG_E: GL16.2 (A1), J1.4
NE_NEG_F: GL14.2 (A1), J1.2
NXA_0: J1.1, NX1.A
NXA_1: J1.3, NX2.A
NXA_2: J1.5, NX3.A
NXA_3: J1.7, NX4.A
NXA_4: J1.9, NX5.A
NXA_5: J1.11, NX6.A
NXA_6: J1.13, NX7.A
NXA_7: J1.15, NX8.A
NXA_8: J1.17, NX9.A
NXA_9: J1.19, NX10.A
NXA_10: J1.21, NX11.A
NXA_11: J1.23, NX12.A
NXA_12: J1.25, NX13.A
NXA_13: J1.27, NX14.A
NXC_0: J1.29, NX1.0, NX2.0, NX3.0, NX4.0, NX5.0, NX6.0, NX7.0, NX8.0, NX9.0, NX10.0, NX11.0, NX12.0, NX13.0, NX14.0, R26.1
NXC_1: J1.31, NX1.1, NX2.1, NX3.1, NX4.1, NX5.1, NX6.1, NX7.1, NX8.1, NX9.1, NX10.1, NX11.1, NX12.1, NX13.1, NX14.1, R17.1
NXC_2: J1.33, NX1.2, NX2.2, NX3.2, NX4.2, NX5.2, NX6.2, NX7.2, NX8.2, NX9.2, NX10.2, NX11.2, NX12.2, NX13.2, NX14.2, R18.1
NXC_3: J1.35, NX1.3, NX2.3, NX3.3, NX4.3, NX5.3, NX6.3, NX7.3, NX8.3, NX9.3, NX10.3, NX11.3, NX12.3, NX13.3, NX14.3, R19.1
NXC_4: J1.37, NX1.4, NX2.4, NX3.4, NX4.4, NX5.4, NX6.4, NX7.4, NX8.4, NX9.4, NX10.4, NX11.4, NX12.4, NX13.4, NX14.4, R20.1
NXC_5: J1.39, NX1.5, NX2.5, NX3.5, NX4.5, NX5.5, NX6.5, NX7.5, NX8.5, NX9.5, NX10.5, NX11.5, NX12.5, NX13.5, NX14.5, R21.1
NXC_6: J1.40, NX1.6, NX2.6, NX3.6, NX4.6, NX5.6, NX6.6, NX7.6, NX8.6, NX9.6, NX10.6, NX11.6, NX12.6, NX13.6, NX14.6, R22.1
NXC_7: J1.38, NX1.7, NX2.7, NX3.7, NX4.7, NX5.7, NX6.7, NX7.7, NX8.7, NX9.7, NX10.7, NX11.7, NX12.7, NX13.7, NX14.7, R23.1
NXC_8: J1.36, NX1.8, NX2.8, NX3.8, NX4.8, NX5.8, NX6.8, NX7.8, NX8.8, NX9.8, NX10.8, NX11.8, NX12.8, NX13.8, NX14.8, R24.1
NXC_9: J1.34, NX1.9, NX2.9, NX3.9, NX4.9, NX5.9, NX6.9, NX7.9, NX8.9, NX9.9, NX10.9, NX11.9, NX12.9, NX13.9, NX14.9, R25.1
unnamed: GL1.1 (A), R1.2
unnamed: GL2.1 (A), R2.2
unnamed: GL3.1 (A), R3.2
unnamed: GL4.1 (A), R4.2
unnamed: GL5.1 (A), R5.2
unnamed: GL6.1 (A), R6.2
unnamed: GL7.1 (A), R7.2
unnamed: GL8.1 (A), R8.2
unnamed: GL9.1 (A), R9.2
unnamed: GL10.1 (A), R10.2
unnamed: GL11.1 (A), R11.2
unnamed: GL12.1 (A), R12.2
unnamed: GL13.2 (A1), GL14.1 (A)
unnamed: GL13.1 (A), R13.2
unnamed: GL15.2 (A1), GL16.1 (A)
unnamed: GL15.1 (A), R14.2
unnamed: GL17.1 (A), R15.2
unnamed: GL18.1 (A), R16.2
unnamed: R17.2, R18.2, R19.2, R20.2, R21.2, R22.2, R23.2, R24.2, R25.2, R26.2

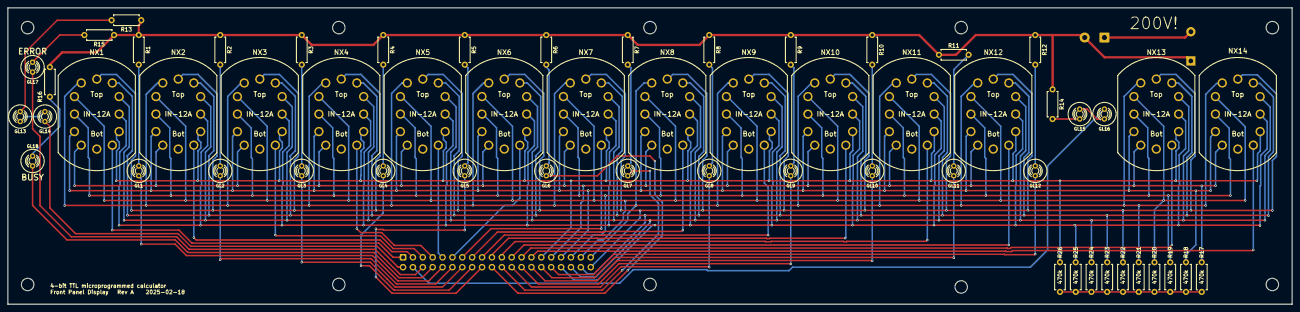
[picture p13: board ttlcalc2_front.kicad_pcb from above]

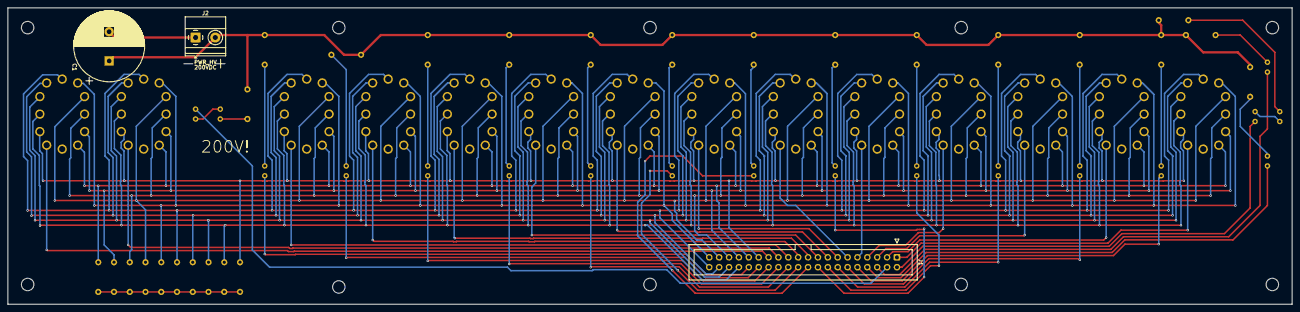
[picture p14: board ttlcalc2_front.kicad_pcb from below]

Board: 2 copper layers, 330.2 x 76.2 mm, 71 parts (3 on the bottom side), 61 nets.

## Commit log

2025-02-13 PCB cleanup
    Swap location of I/O output register and address latch
    Clean up routing
    Via stitch around clock traces
    Fill out sheet description block
    [ttlcalc2.kicad_sch, ttlcalc2_bypass.kicad_sch]
2025-02-13 Moved logic board files into subdirectory
    [ttlcalc2.kicad_sch, ttlcalc2_bypass.kicad_sch]
2025-02-13 Add in-progress display schematic
    [ttlcalc2_display.kicad_pcb, ttlcalc2_display.kicad_sch, ttlcalc2_display_digit_store.kicad_sch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]
2025-02-14 Memory and I/O timing improvements
    Changed memory /WE to use combination of /CLK2 and /WMem to ensure /WE is de-asserted well before memory address becomes invalid
    Removed memory data input register, made unnecessary by above change
    Changed I/O output register to buffer (same reasons above)
    Fixed and updated date on PCB silkscreen
    [ttlcalc2.kicad_sch]
2025-02-15 Continue work on display driver board schematic
    [ttlcalc2_display.kicad_sch, ttlcalc2_display_digit_store.kicad_sch, ttlcalc2_display_dps.kicad_sch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]
2025-02-16 Simplify display driver board, add busy light
    Removed digit storage and multiplexing logic from display driver, will handle in software instead
    Add driver for busy indicator
    [ttlcalc2_display.kicad_sch, ttlcalc2_display_dps.kicad_sch, ttlcalc2_display_nx_anode_drive.kicad_sch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]
2025-02-16 Minor simplifications and ERC fix
    Fix missing NE_BUSY from bus definition
    Switch 74LS139 to 74LS138
    Remove extra bypass caps
    [ttlcalc2_display.kicad_sch, ttlcalc2_display_dps.kicad_sch, ttlcalc2_display_nx_anode_drive.kicad_sch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]
2025-02-18 Display driver board routing and silkscreen tweaks
    [ttlcalc2_display.kicad_pcb, ttlcalc2_display.kicad_sch, ttlcalc2_display_dps.kicad_sch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]
2025-02-18 Display driver geographical reannotate
    [ttlcalc2_display.kicad_pcb, ttlcalc2_display.kicad_sch, ttlcalc2_display_dps.kicad_sch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]
2025-02-19 Commit front panel display board schematic and PCB
    [ttlcalc2_front.kicad_pcb, ttlcalc2_front.kicad_sch]
2025-02-19 Minor routing tweaks to front panel display
    [ttlcalc2_front.kicad_pcb]
2025-02-24 Convert to KiCad 9.0
    Convert to KiCad 9.0 format
    Tweak silkscreen to fix DRC errors introduced by updated footprints
    [ttlcalc2_front.kicad_pcb, ttlcalc2_front.kicad_sch]
2025-02-27 Minor display hardware revisions
    Add anti-ghosting inter-cathode resistors to nixies
    Adjust component values based on experiments
    Change from individual netclass labels to rule areas
    Tweak traces on display board
    Update .gitignore to ignore KiCad lock files
    [ttlcalc2_display.kicad_pcb, ttlcalc2_display.kicad_sch, ttlcalc2_display_dps.kicad_sch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]
2025-02-28 More resistor value updates, ERC fixes
    Update Nixie anode resistors to 22k based on calculation and experimental verification
    Fix ERC errors due to remaining Logic netclass labels in decimal point sheet
    [ttlcalc2_display.kicad_pcb, ttlcalc2_display_dps.kicad_sch, ttlcalc2_display_nx_anode_drive.kicad_sch]
2025-03-05 Software: Add customasm assembly files
2025-03-10 README: Add links, PCB renders
2026-10-22 Simulator: Add program test harness and end-to-end instruction tests
    - TtlCalcSim.Testing assembles programs with customasm and runs them in a TestMachine with step limits, symbol lookup, and scripted I/O
    - TtlCalcSim.ProgramTests covers fib.asm and checks every instruction against a reference model written from the docs
